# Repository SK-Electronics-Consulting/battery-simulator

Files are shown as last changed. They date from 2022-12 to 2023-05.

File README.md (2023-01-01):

# Battery Simulator

When developing new hardware, engineers often need to see how the device will perform while running on battery power. 
Because it is not always convenient to use real batteries for testing, battery simulators have been developed. 
However, commercial battery simulators are expensive, sometimes costing well into the thousands of dollars. 
As an alternative, I have developed an open-source battery simulator that can be built in a home workshop for under $100. 

A battery simulator is a piece of text equipment which does exactly that, simulates a battery. 
The main difference between a battery simulator and a "general purpose" power supply is that the power supply will only source current at a positive voltage, while the battery simulator will both source and sink current also at a positive voltage. 
If you map this capability out to a [Cartesian Plane](https://en.wikipedia.org/wiki/Quadrant_(plane_geometry)), you can use the quadrants as a short-hand way of describing the capability of the device. 
A general purpose power supply (e.g. [Siglent SPD1000X](https://siglentna.com/power-supplies/spd1000x-series-programmable-dc-power-supply/)) is a 1-quadrant power supply because it can only source current and can only do positive voltage. 
A battery simulator like the [Keithley 2302](https://www.tek.com/en/datasheet-/model-2302-battery-simulator-models-2306-and-2306-pj-battery-chargers-simulato) is a 2-quadrant supply because it operates only at a positive voltage, but can source (positive) or sink (negative) current. 
An example of a 4-quadrant power supply would be an SMU (Source Measure Unit) like the [Keithley 2400](https://www.tek.com/en/products/keithley/source-measure-units/2400-graphical-series-sourcemeter). 

> NOTE: Terms like battery simulator, SMU, and power supply may imply a certain number of quadrants, but unfortunately it is not guaranteed.  Always check the datasheet to make sure it's not a marketing term.  

The goal of this project is to make an open-source, lowish-cost battery simulator. This is both to give people access to using devices like this, but also as a design exercise in analog design.  

# Requirements
1. Device shall simulate a single cell Lithium Ion battery, so a voltage of 2.0 V - 4.4 V
1. Device shall have a current output of 1A, both sourcing and sinking.
1. Device shall be powered by an external power supply. 

# Phases
## Phase 1
Create a circuit that will operate as a 2-quadrant power supply.  This might be as simple as using a high-power output op-amp and a potentiometer. 

* TODO: Check if the op-amp will sink current in addition to sourcing. 

### Design Output

The [OPA569](https://www.ti.com/lit/ds/symlink/opa569.pdf) was selected as an available (yaaay chip shortage!) high power op-amp. 
It has some nifty features that are on the [wishlist](#future-phase-wishlist) while satisfying the basic needs of this phase. 
It has a 2A output, along with a 300mV drop-out at 2A. This means that assuming a 5V source (USB or the like), it can maintain it's output at 4.7V, which is well above the 4.2-4.4V max needed simulating 1S Lithium cells. 
This chip does leave some room for improvement.  It has a surprisingly high quiescent current, especially one that varies with current limit.  

### Limitations of Phase 1

* The OPA569 has a max voltage of 5.5V, so only 1S Lithium batteries will be doable.
* Current Monitor pin can only indicate sourcing current.  This could be fixed a couple ways, but is going to stay out of scope for this phase. 

## Future Phase Wishlist

These are features that will be added in future versions.  The list is roughly in order of priority.  

1. USB-C Power Supply
1. Current Monitor Output (Analog to a scope.  Need to define bandwidth required)
1. A good UI (MCU + screen + knob/buttons?)
1. Adding ESR to the current path.  
1. Programmability for adding smarts.  
    1. Voltage limits based on chemistry.  (e.g. 0.5-1.5V for Alkaline, 2.0-4.4V for Lithium-Ion, 1.0-1.2V for NiMH)
    1. Ability to simulate actual charging and discharging based on pre-made curves and a user-defined capacity
1. Considering moving away from an op-amp design, and moving towards a more bespoke and power efficient design.  
1. It might be cool to add "between cells" taps to allow multi-cell chargers who do cell balancing to operate correctly. 

# Out of scope

1. At the moment, this device will not have a way to be adjusted for the sake of calibration.  Not to say this is impossible, but for an open-source, low-cost project, this is unnecessary.
1. This device will never have a need for [4 quadrant operation](https://edadocs.software.keysight.com/kkbopen/what-is-a-bipolar-four-quadrant-power-supply-583425137.html)

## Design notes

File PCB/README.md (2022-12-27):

# battery simulator PCB

[Replace these texts and sections as needed.  This file should desribe the PCB, and associated information.]

## Background

[Fill this out with general info]

## [Next Section]

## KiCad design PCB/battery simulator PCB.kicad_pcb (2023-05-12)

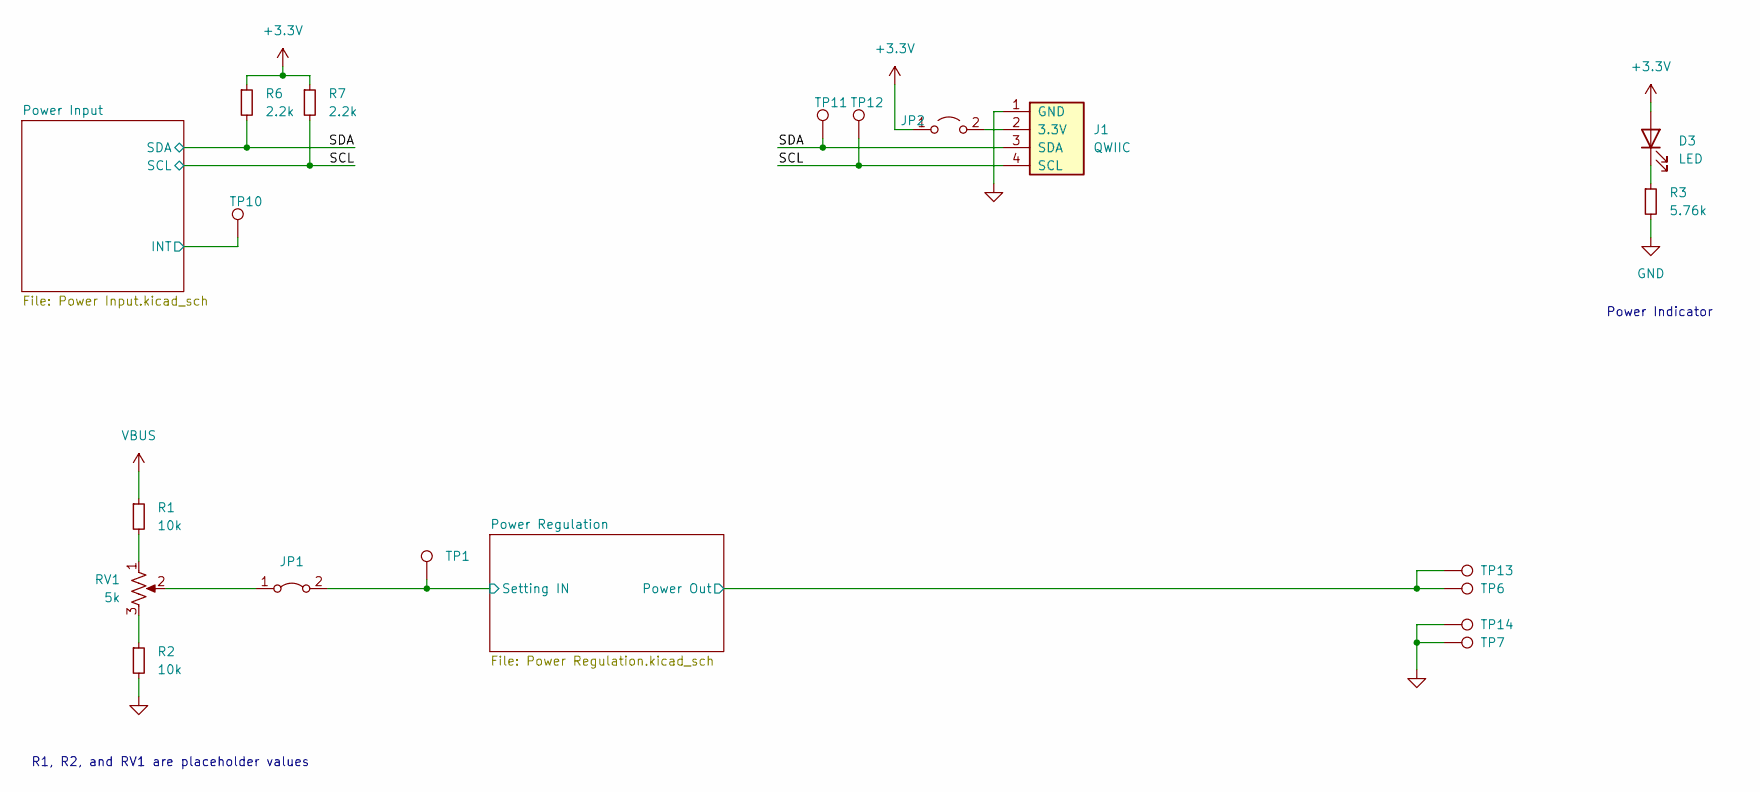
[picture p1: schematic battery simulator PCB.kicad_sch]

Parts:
D3: LED; LED_0603_1608Metric_Pad1.05x0.95mm_HandSolder
J1: QWIIC; JST_SH_SM04B-SRSS-TB_1x04-1MP_P1.00mm_Horizontal
JP1: Jumper_2_Bridged; SolderJumper-2_P1.3mm_Bridged_RoundedPad1.0x1.5mm
JP2: Jumper_2_Open; PinHeader_1x02_P2.54mm_Vertical
R1, R2: 10k; R_0402_1005Metric_Pad0.72x0.64mm_HandSolder
R3: 5.76k; R_0402_1005Metric_Pad0.72x0.64mm_HandSolder
R6, R7: 2.2k; R_0402_1005Metric_Pad0.72x0.64mm_HandSolder
RV1: 5k; Potentiometer_Bourns_3296W_Vertical
TP1, TP10, TP11, TP12: TestPoint; TestPoint_Keystone_5000-5004_Miniature
TP6, TP7, TP13, TP14: TestPoint; SolderWire-1sqmm_1x01_D1.4mm_OD2.7mm

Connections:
+3.3V: D3.2 (A), JP2.1 (A), R6.1, R7.1; also elsewhere on the board
/Power Input/INT: TP10.1; also elsewhere on the board
/Power Regulation/Power Out: TP6.1, TP13.1; also elsewhere on the board
/Power Regulation/Setting IN: JP1.2 (B), TP1.1; also elsewhere on the board
/SCL: J1.4 (SCL), R7.2, TP12.1; also elsewhere on the board
/SDA: J1.3 (SDA), R6.2, TP11.1; also elsewhere on the board
GND: J1.1 (GND), R2.2, R3.2, TP7.1, TP14.1; also elsewhere on the board
unnamed: D3.1 (K), R3.1
unnamed: J1.2 (3.3V), JP2.2 (B)
unnamed: JP1.1 (A), RV1.2
unnamed: R1.2, RV1.1
unnamed: R2.1, RV1.3
VBUS: R1.1; also elsewhere on the board

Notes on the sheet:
R1, R2, and RV1 are placeholder values
Power Indicator

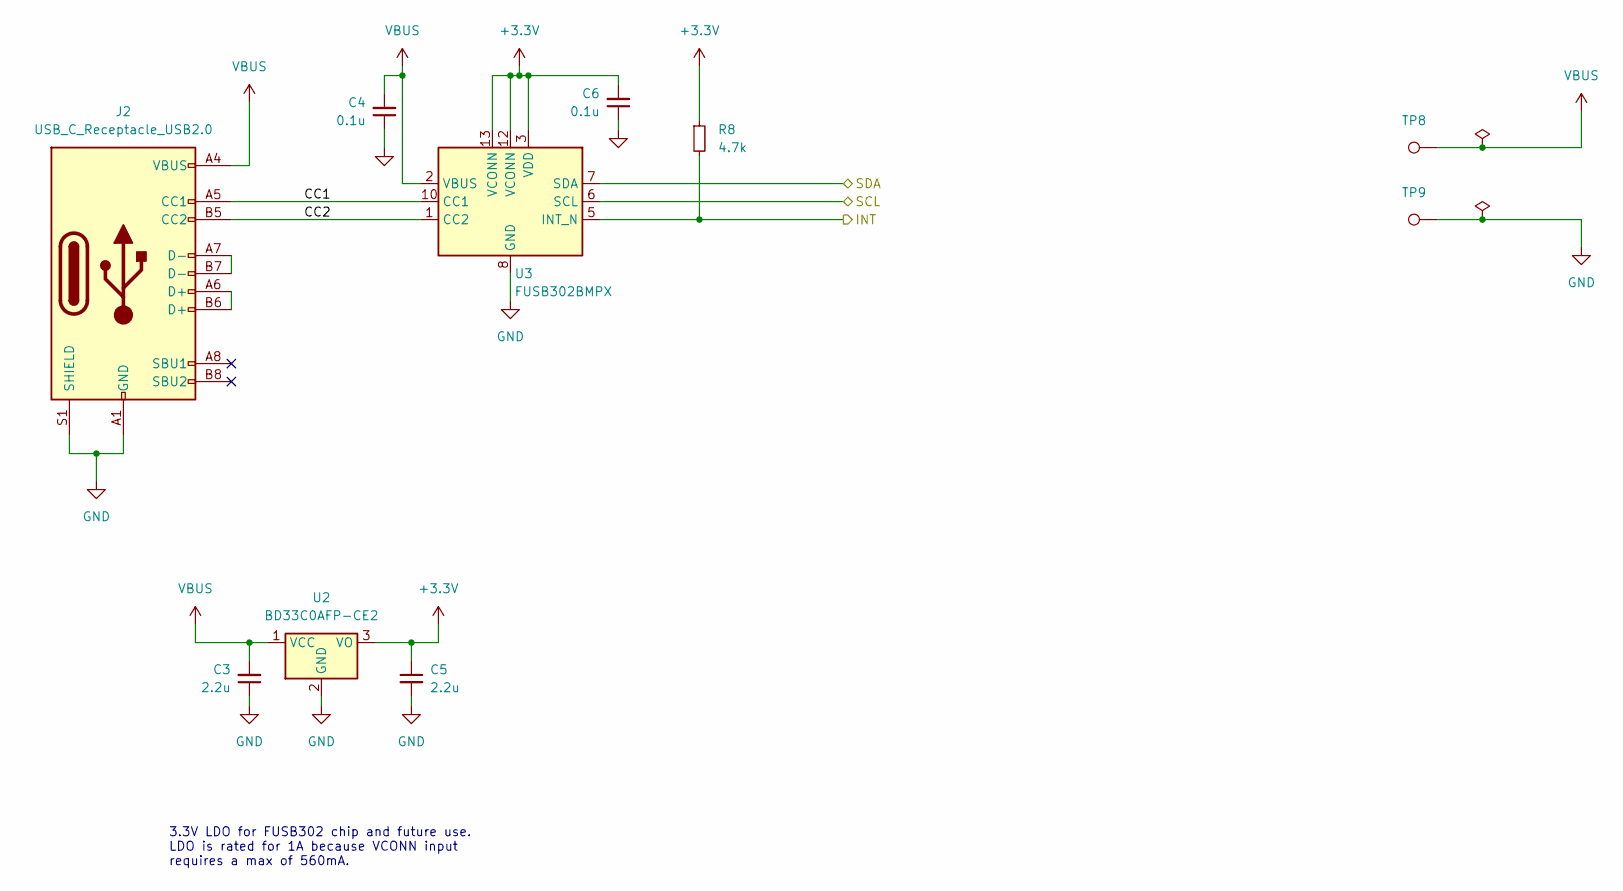
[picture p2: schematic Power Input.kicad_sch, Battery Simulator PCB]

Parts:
C3, C5: 2.2u; C_0805_2012Metric
C4, C6: 0.1u; C_0402_1005Metric_Pad0.74x0.62mm_HandSolder
J2: USB_C_Receptacle_USB2.0; USB_C_Receptacle_GCT_USB4085
R8: 4.7k; R_0402_1005Metric_Pad0.72x0.64mm_HandSolder
TP8, TP9: TestPoint; SolderWire-1sqmm_1x01_D1.4mm_OD2.7mm
U2: BD33C0AFP-CE2; TO-252-2
U3: FUSB302BMPX; WQFN-14-1EP_2.5x2.5mm_P0.5mm_EP1.45x1.45mm

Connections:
+3.3V: C5.1, C6.2, R8.1, U2.3 (VO), U3.3 (VDD), U3.4 (VDD), U3.12 (VCONN), U3.13 (VCONN); also elsewhere on the board
/Power Input/CC1: J2.A5 (CC1), U3.10 (CC1), U3.11 (CC1)
/Power Input/CC2: J2.B5 (CC2), U3.1 (CC2), U3.14 (CC2)
/Power Input/INT: R8.2, U3.5 (INT_N); also elsewhere on the board
/SCL: U3.6 (SCL); also elsewhere on the board
/SDA: U3.7 (SDA); also elsewhere on the board
GND: C3.1, C4.1, C5.2, C6.1, J2.A1 (GND), J2.A12 (GND), J2.B1 (GND), J2.B12 (GND), J2.S1 (SHIELD), TP9.1, U2.2 (GND), U3.8 (GND), U3.9 (GND), U3.15 (GND); also elsewhere on the board
unnamed: J2.A6 (D+), J2.B6 (D+)
unnamed: J2.A7 (D-), J2.B7 (D-)
VBUS: C3.2, C4.2, J2.A4 (VBUS), J2.A9 (VBUS), J2.B4 (VBUS), J2.B9 (VBUS), TP8.1, U2.1 (VCC), U3.2 (VBUS); also elsewhere on the board

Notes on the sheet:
3.3V LDO for FUSB302 chip and future use. LDO is rated for 1A because VCONN input requires a max of 560mA.

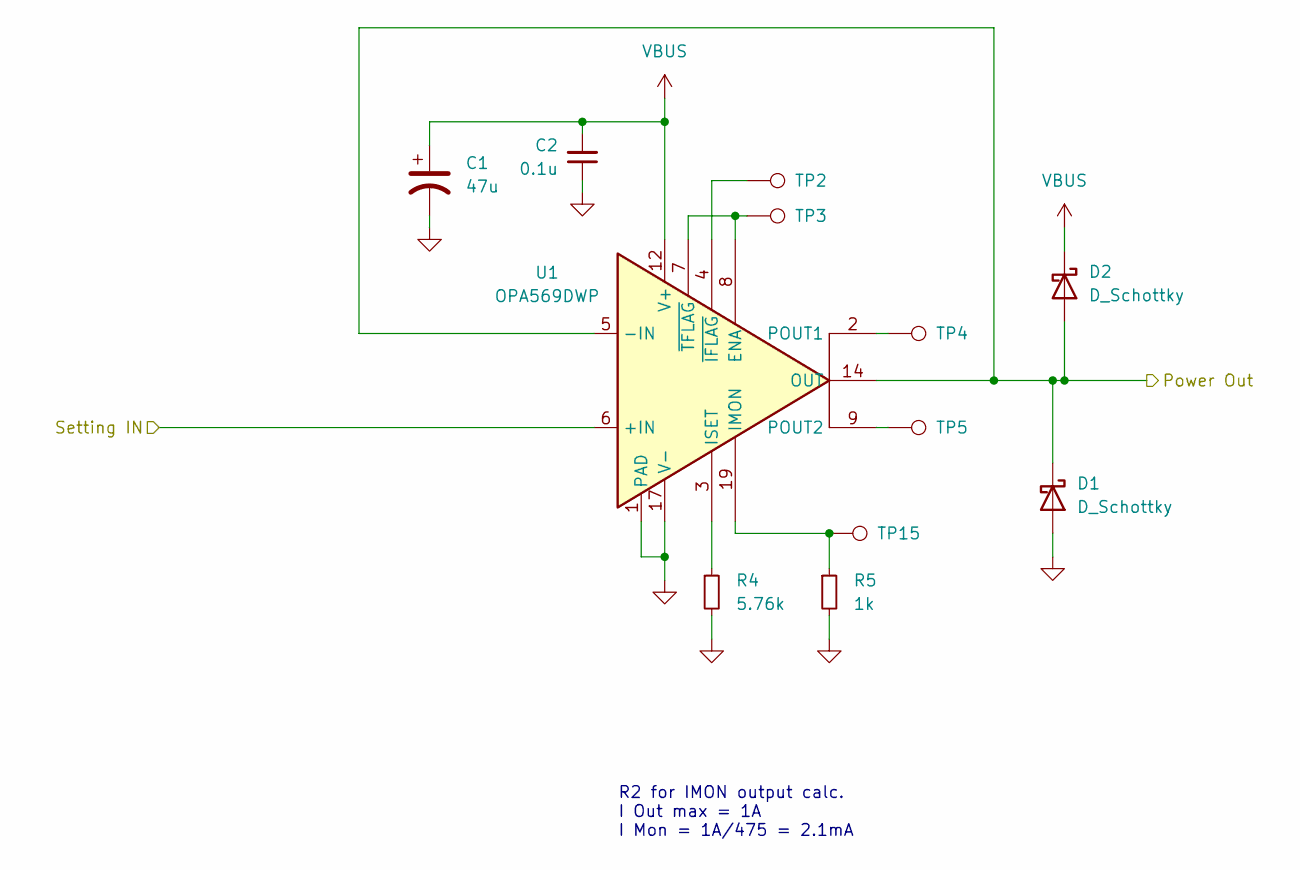
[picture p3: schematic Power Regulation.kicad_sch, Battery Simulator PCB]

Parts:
C1: 47u; CP_EIA-6032-20_AVX-F_Pad2.25x2.35mm_HandSolder
C2: 0.1u; C_0402_1005Metric_Pad0.74x0.62mm_HandSolder
D1, D2: D_Schottky; D_SMA-SMB_Universal_Handsoldering
R4: 5.76k; R_0402_1005Metric_Pad0.72x0.64mm_HandSolder
R5: 1k; R_0402_1005Metric_Pad0.72x0.64mm_HandSolder
TP2, TP3, TP4, TP5, TP15: TestPoint; TestPoint_Keystone_5000-5004_Miniature
U1: OPA569DWP; SO-20-1EP_7.52x12.825mm_P1.27mm_EP6.045x12.09mm_Mask3.56x4.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

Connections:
/Power Regulation/Power Out: D1.1 (K), D2.2 (A), U1.5 (-IN), U1.14 (OUT), U1.15 (OUT); also elsewhere on the board
/Power Regulation/Setting IN: U1.6 (+IN); also elsewhere on the board
GND: C1.2, C2.1, D1.2 (A), R4.2, R5.2, U1.1 (PAD), U1.10 (PAD), U1.11 (PAD), U1.17 (V-), U1.18 (V-), U1.20 (PAD), U1.21 (PAD); also elsewhere on the board
unnamed: TP3.1, U1.7 (~TFLAG), U1.8 (ENA)
unnamed: R5.1, TP15.1, U1.19 (IMON)
unnamed: R4.1, U1.3 (ISET)
unnamed: TP4.1, U1.2 (POUT1)
unnamed: TP5.1, U1.9 (POUT2)
unnamed: TP2.1, U1.4 (~IFLAG)
VBUS: C1.1, C2.2, D2.1 (K), U1.12 (V+), U1.13 (V+); also elsewhere on the board

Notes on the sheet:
R2 for IMON output calc. I Out max = 1A I Mon = 1A/475 = 2.1mA

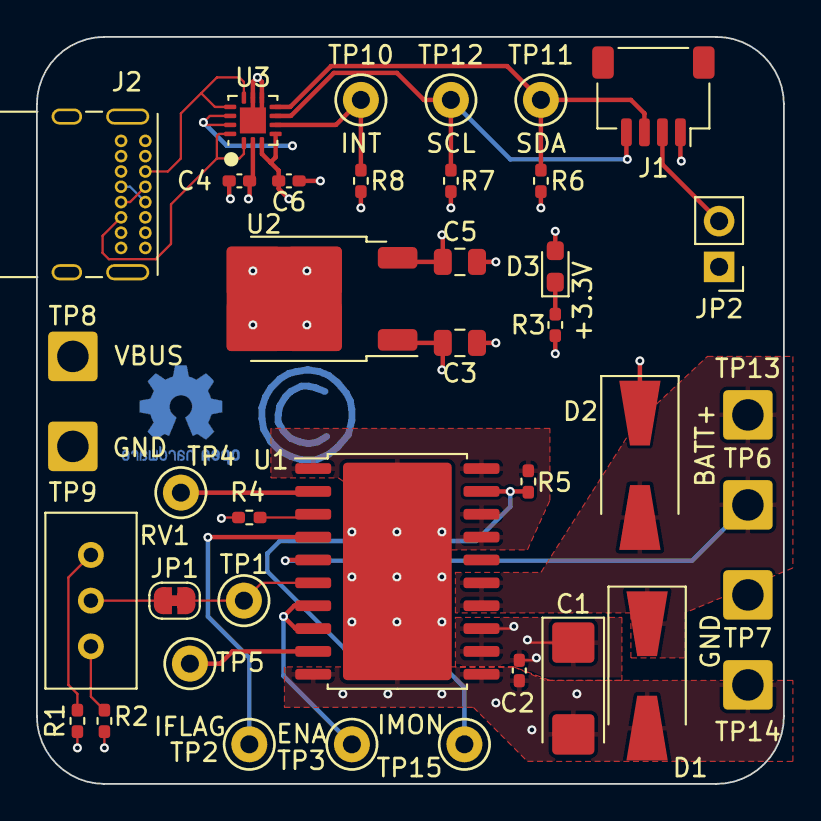
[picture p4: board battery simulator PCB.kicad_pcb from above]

Board: 4 copper layers, 41.5 x 41.5 mm, 40 parts (0 on the bottom side), 23 nets.

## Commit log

2022-12-22 Update README with a general project plan, and gitignore.
    Updated the README with a general project plan. Also added
    phases section along with future improvements.
    Updated gitignore with KiCAD v6 info.
2022-12-27 Completed op-amp circuit and basic power. Also updated README.
    Picked the op-amp and implemented that into the schematic.
    Selected basic placeholder components for power input and output.
    Updated README with relevant info.
    TODO: Consider going straight for USB power source.
    TODO: PCB Layout.
    [Power Input.kicad_sch, Power Regulation.kicad_sch, battery simulator PCB.kicad_pcb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]
2023-01-01 Updated README.md with more info and some formating changes.
    Updated README with more info about battery simulators, some
    details, and other formatting.
    Thanks to @emilyvelasco for the edits and suggestions.
2023-01-14 Added FUSB302B and associated circuitry.
    Added FUSB302B, along with USB-C Connector and LDO. The LDO is
    needed to power the FUSB302B from the cable.
    Also added some debugging and convenience items such as a QWIIC
    connector and some test points.
    [Power Input.kicad_sch, Power Regulation.kicad_sch, battery simulator PCB.kicad_pcb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]
2023-01-14 Imported and placed all components into PCB.
    Imported all components into PCB. Finalized PCB outline to 50mm x
    50mm square. Arranged all components into reasonable locations
    and added 2 planes.
    Schematic update is just adding netlabels to the CC1 and CC2 nets.
    [Power Input.kicad_sch, battery simulator PCB.kicad_pcb]
2023-05-12 Update to KiCAD v7, and finalize for V1 build
    Updated to KiCAD v7, which touched many files.
    Also made some changes to finalize board for prototype build. Simplified the
    circuit a bit to just something built and tested.
    [Power Input.kicad_sch, Power Regulation.kicad_sch, battery simulator PCB.kicad_pcb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]
